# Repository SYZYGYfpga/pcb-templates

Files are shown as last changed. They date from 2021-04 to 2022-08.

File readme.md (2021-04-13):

# SYZYGY PCB Templates

This repository contains schematics, PCB files and part libraries to use as a template for creating SYZYGY compliant peripherals. 

[More Information About SYZYGY](https://syzygyfpga.io/)

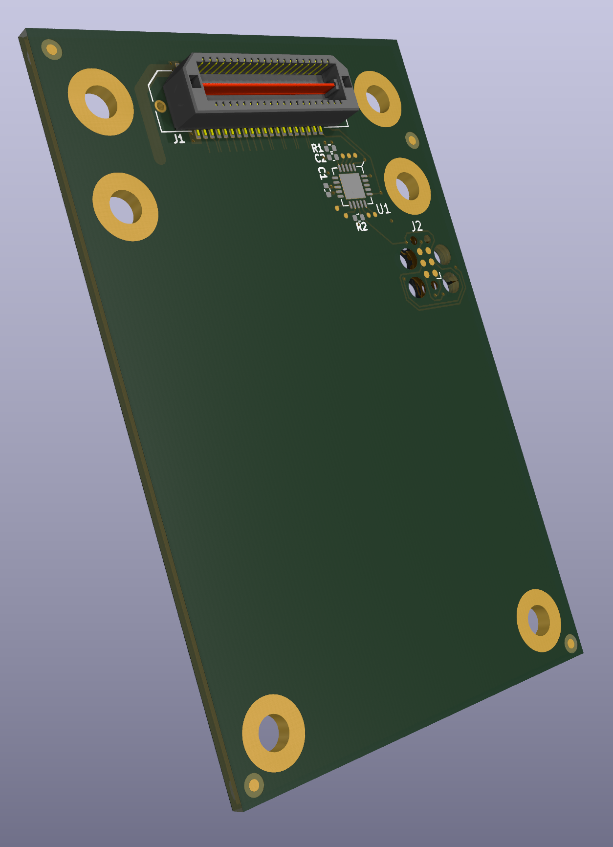
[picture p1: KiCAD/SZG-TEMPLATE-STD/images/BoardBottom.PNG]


## Template Contains

* SYZYGY Standard and Transceiver Connectors
* MCU for SYZYGY DNA Support
* Programming Connector (Tag-Connect)
* Standard Mechanical Configuration (Board length can be adjusted as necessary)

## Tag-Connect Programming Header

The programming connection for the SYZYGY DNA MCU uses a connector-less [Tag-Connect header](https://www.tag-connect.com/). A wired connector with spring loaded contacts clips onto the board and connects to the headers exposed pads. The template's header design allows a programming connection from either side of the board.

The template boards support either the TC2030 or TC2030-NL. The exact cable model will depend on the programmer you are using as this changes the pinout and connector on the other end of the cable.

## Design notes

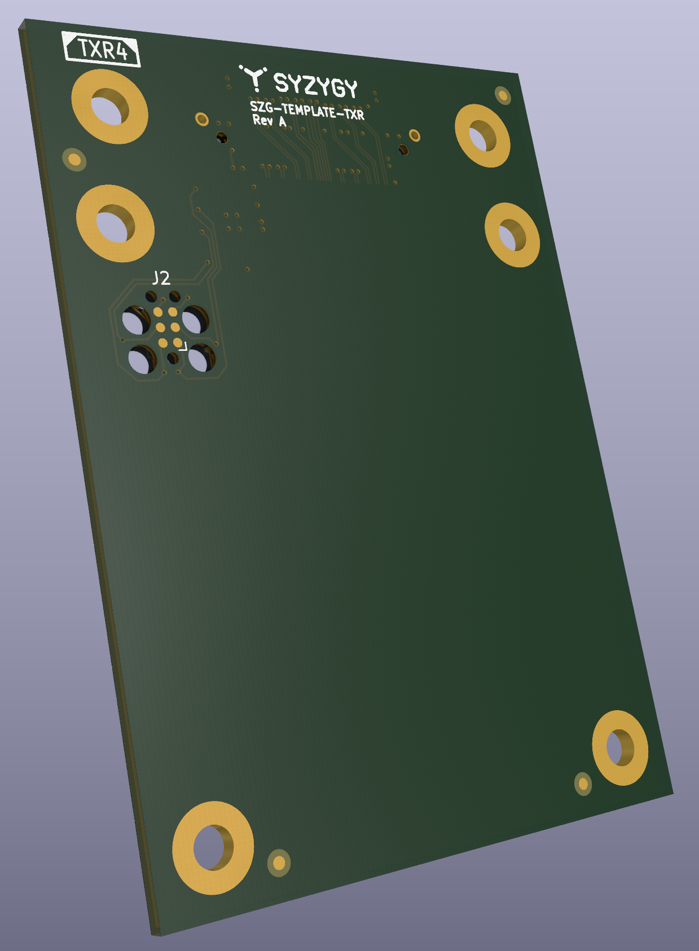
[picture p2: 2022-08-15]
KiCAD/SZG-TEMPLATE-TXR/images/BoardTop.PNG

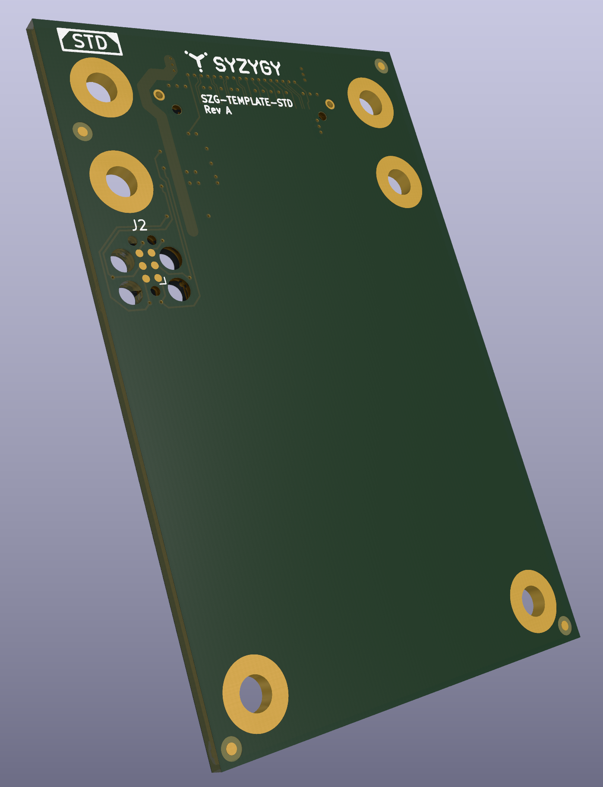
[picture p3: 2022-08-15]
KiCAD/SZG-TEMPLATE-STD/images/BoardTop.PNG

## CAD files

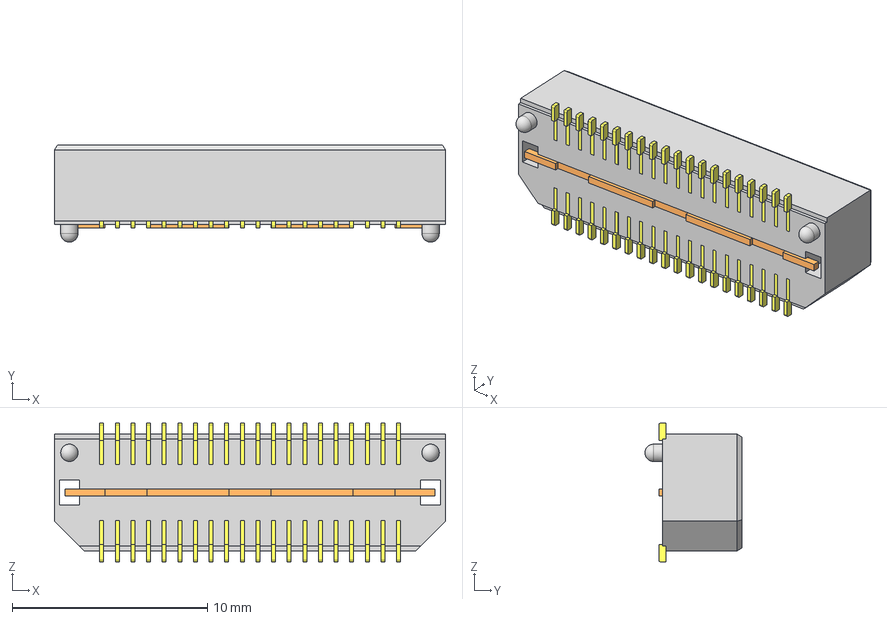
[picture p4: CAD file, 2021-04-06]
KiCAD/3D/QTE-020-01-F-D-A.stp
20.0 x 4.98 x 7.11 mm
_QTE-020-01-F-D-At
_PT-1S39-01(020-01-D)
_QTE-T-1G1-01_imp

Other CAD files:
KiCAD/3D/QTH-020-01-F-D-DP-A.stp

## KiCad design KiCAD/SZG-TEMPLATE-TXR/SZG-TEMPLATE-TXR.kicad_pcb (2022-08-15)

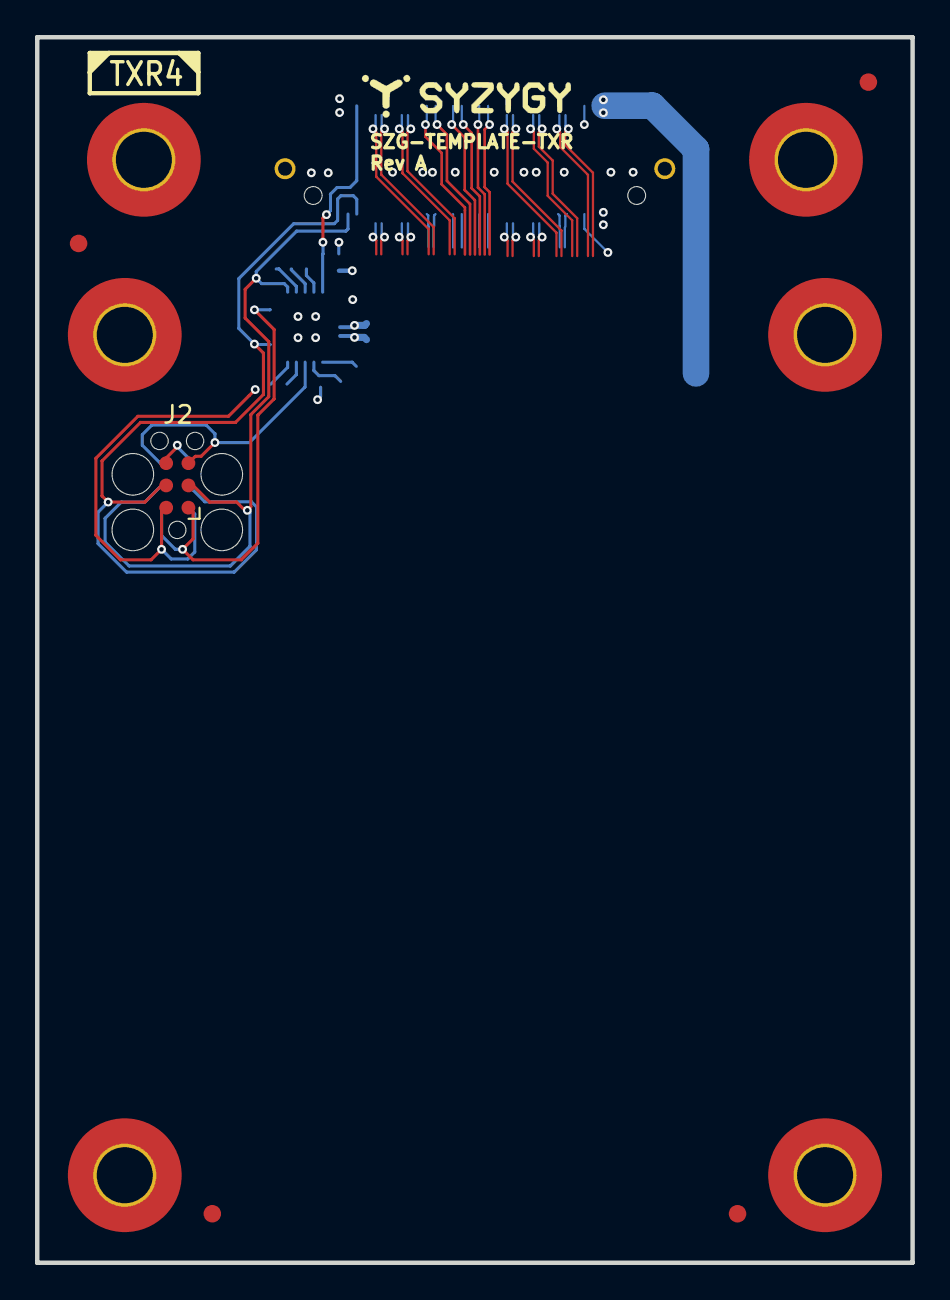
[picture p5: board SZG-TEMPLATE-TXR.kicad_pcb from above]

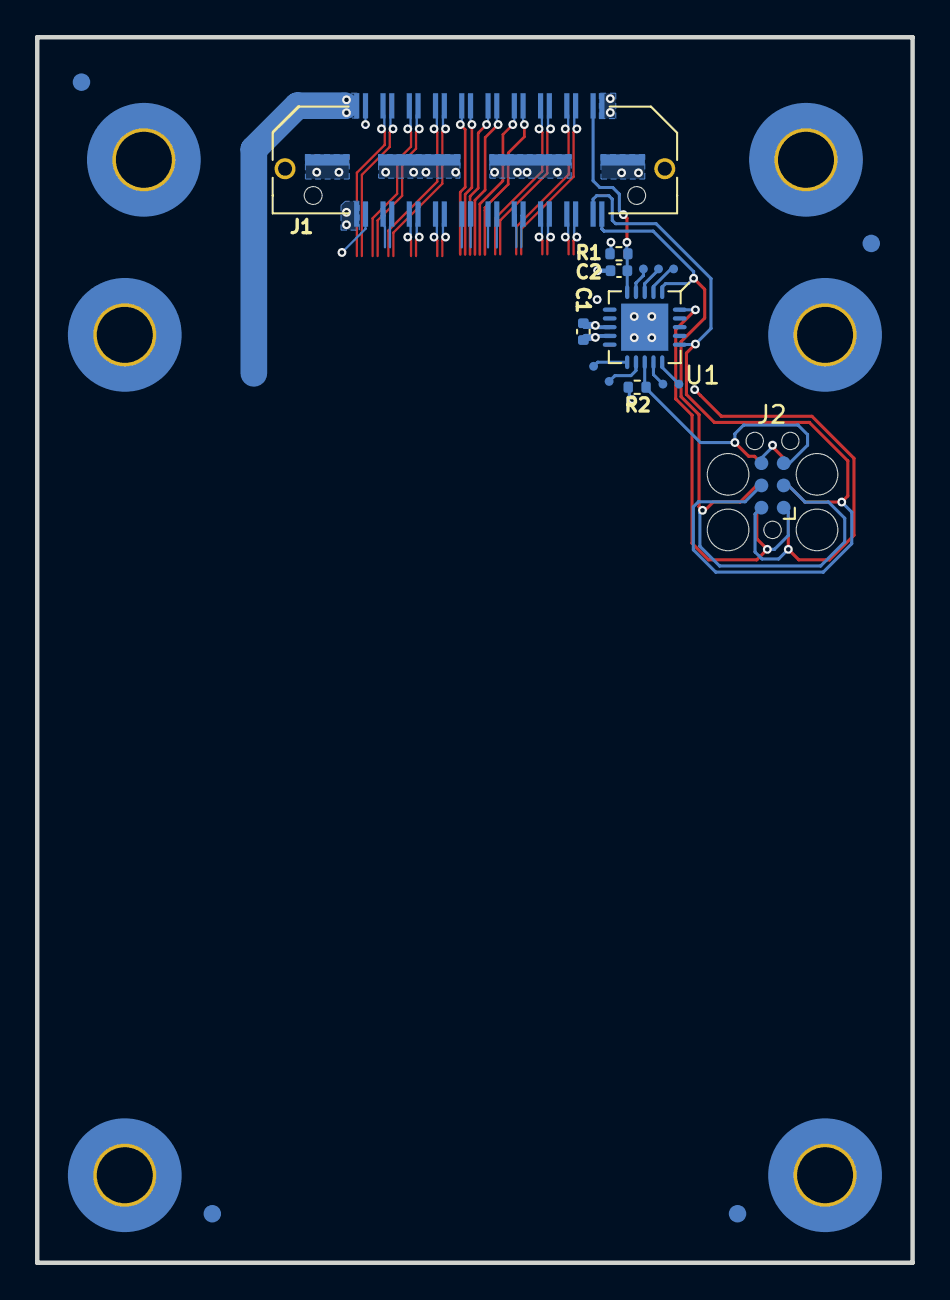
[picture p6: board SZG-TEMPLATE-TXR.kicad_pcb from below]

Board: 4 copper layers, 50.0 x 70.0 mm, 29 parts (17 on the bottom side), 14 nets.

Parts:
*1: Opal Kelly Logo; okLogo-23x5
C1: 0.1uF; C_0402_1005Metric
C2: 0.1uF DNP; C_0402_1005Metric
FID1, FID2, FID3, FID4, FID5, FID6, FID7, FID8: Fiducial; Fiducial_1mm_Mask2mm
H1, H2, H3, H4, H5, H6: MountingHole_Pad; MountingHole_3.2mm_M3_6.5mm_Pad_TopBottom
J1: SYZYGY_TXR-4; QTH-020-01-F-D-DP-A
J2: Conn_01x06; Tag-Connect_TC2030-IDC-FP_2x03_P1.27mm_Vertical
R1, R2: 10K; R_0402_1005Metric
TP5, TP6, TP7, TP8, TP9, TP10, TP11: TestPoint; TestPoint-20mil
U1: ATtiny44A-MU; QFN-24-4x4mm

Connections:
+3V3: C1.1, J1.40 (+3.3V), J2.2, R1.1, R2.1, U1.9 (VCC)
/MCU_MISO: J2.1, U1.20 (PA5)
/MCU_RESET_B: J2.5, R2.2, U1.13 (~RESET/PB3)
/MCU_SCL_USCK: J1.1 (SCL), J2.3, U1.1 (PA4)
/MCU_SDA_MOSI: J1.3 (SDA), J2.4, U1.16 (PA6)
/R_GA: C2.1, J1.4 (R_GA), R1.2, U1.5 (AREF/PA0)
GND: C1.2, C2.2, J1.0 (GND), J2.6, U1.8 (GND), U1.21 (GND)
unnamed: TP5.1, U1.11 (XTAL1/PB0)
unnamed: TP6.1, U1.4 (PA1)
unnamed: TP7.1, U1.12 (XTAL2/PB1)
unnamed: TP8.1, U1.3 (PA2)
unnamed: TP9.1, U1.14 (PB2)
unnamed: TP10.1, U1.2 (PA3)
unnamed: TP11.1, U1.15 (PA7)

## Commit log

2021-04-06 Initial commit. Adding KiCAD template projects for SYZYGY Standard and Transceiver pods.
    [QTE-020-01-F-D-A.stp, QTH-020-01-F-D-DP-A.stp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]
2021-04-12 Corrected a net name. Improved example SYZYGY connector breakout routing for TXR board.
    [SZG-TEMPLATE-TXR.kicad_pcb, SZG-TEMPLATE-TXR.sch]
2021-04-13 Adjusted the readme board image size.
2021-04-13 Adding Altium template project files.
    [SZG-TEMPLATE-STD.PRJPCB, SZG-TEMPLATE-STD.PcbDoc, SZG-TEMPLATE-STD.SchDoc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]
2021-04-14 Updated the template projects MCU programming header to use the standard Tag-Connect cable pin order.
    [SZG-TEMPLATE-STD-B_Cu.gbr, SZG-TEMPLATE-STD-B_Mask.gbr, SZG-TEMPLATE-STD-B_Paste.gbr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]
2021-05-24 Updated Tag-Connect header footprint to remove paste mask openings.
    [SZG-TEMPLATE-STD.PcbDoc, SZG-TEMPLATE-TXR.PcbDoc]
2021-05-24 Improved SYZYGY TXR4 example breakout routing.
    [SZG-TEMPLATE-TXR.PcbDoc]
2022-08-04 Updated SZG-TEMPLATE-STD to KiCAD v6. Added STD port silk logo.
    [SZG-TEMPLATE-STD-B_Cu.gbr, SZG-TEMPLATE-STD-B_Mask.gbr, SZG-TEMPLATE-STD-B_Paste.gbr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]
2022-08-04 Fixed SZG-TEMPLATE-TXR board and mounting hole dimensions. Added TXR4 logo. Updated board images.
    [SZG-TEMPLATE-STD.kicad_pcb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]
2022-08-04 Added the STD and TXR4 silk logo to Altium template PCBs.
    [SZG-TEMPLATE-STD.PcbDoc, SZG-TEMPLATE-TXR.PcbDoc]

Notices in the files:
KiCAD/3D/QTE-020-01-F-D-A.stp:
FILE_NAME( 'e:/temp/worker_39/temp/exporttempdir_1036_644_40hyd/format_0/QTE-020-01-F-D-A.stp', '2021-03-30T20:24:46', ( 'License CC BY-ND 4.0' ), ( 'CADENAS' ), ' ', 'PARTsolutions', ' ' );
